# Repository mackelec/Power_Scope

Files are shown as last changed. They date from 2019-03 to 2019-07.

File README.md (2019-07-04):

# Power_Scope
Power Scope for $10

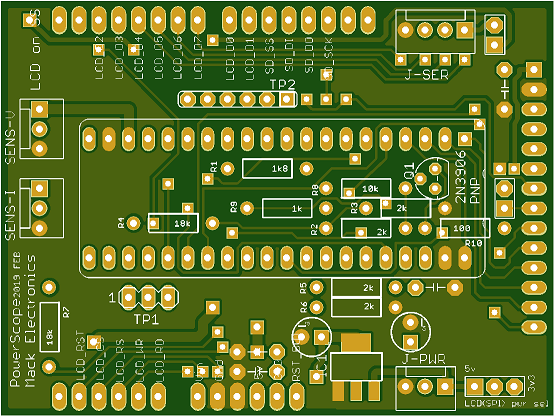
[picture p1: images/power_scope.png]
Power_Scope


https://www.thebackshed.com/forum/forum_posts.asp?TID=11123&PN=1

Software is still a work in progress.

A minimal Oscilloscope design utilising a STM32F103 "Blue Pill" and a cheap mcuFriend 2.4" LCD, specifically to display the output voltage for an Inverter.  Along with displaying th eAc waveform it will display RMS voltage, Current and Power.

LCD library is compatible with the 8bit mcuFriend 2.4" and 3.5" LCD.

PCD features:

PCB is compatible with the 8 bit mcuFriend "UNO" lcds as well as the SPI based LCDs.

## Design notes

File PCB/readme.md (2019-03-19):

"PowerScope_004_PCB_Order_20190317.zip"  contains the files sent for PCB manufacture.

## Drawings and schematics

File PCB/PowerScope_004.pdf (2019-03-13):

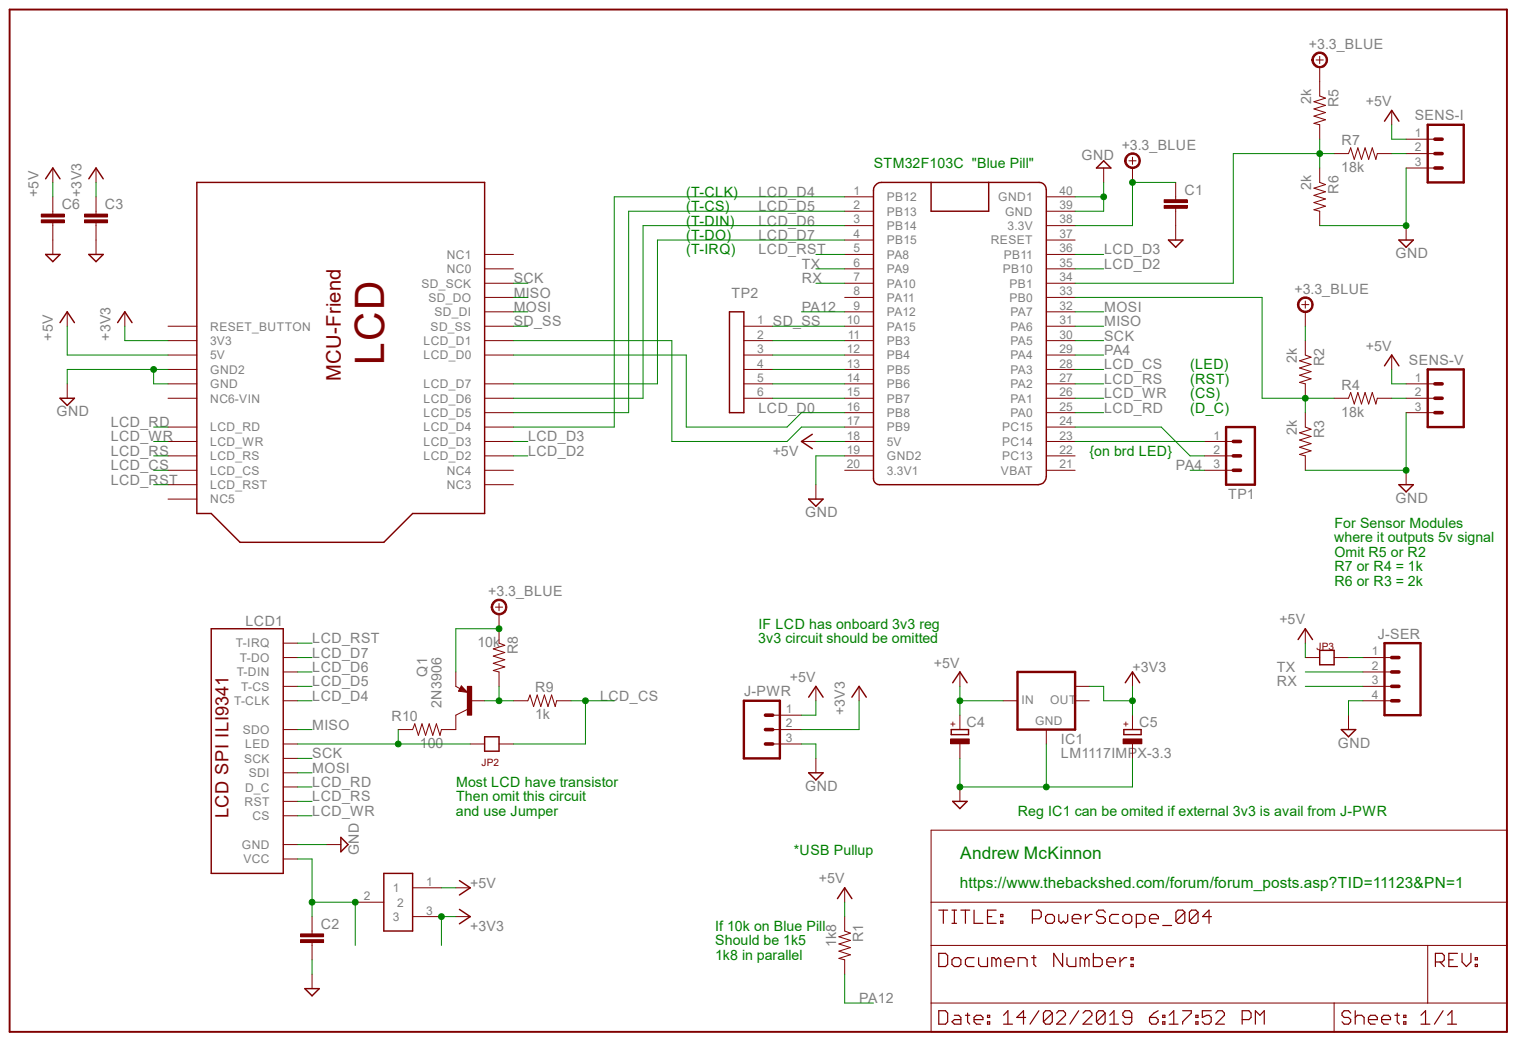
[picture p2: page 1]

For Sensor Modules
where it outputs 5v signal
Omit R5 or R2

IF LCD has onboard 3v3 reg
3v3 circuit should be omitted

Most LCD have transistor
Then omit this circuit

https://www.thebackshed.com/forum/forum_posts.asp?TID=11123&PN=1

If 10k on Blue Pill
Should be 1k5
1k8 in parallel

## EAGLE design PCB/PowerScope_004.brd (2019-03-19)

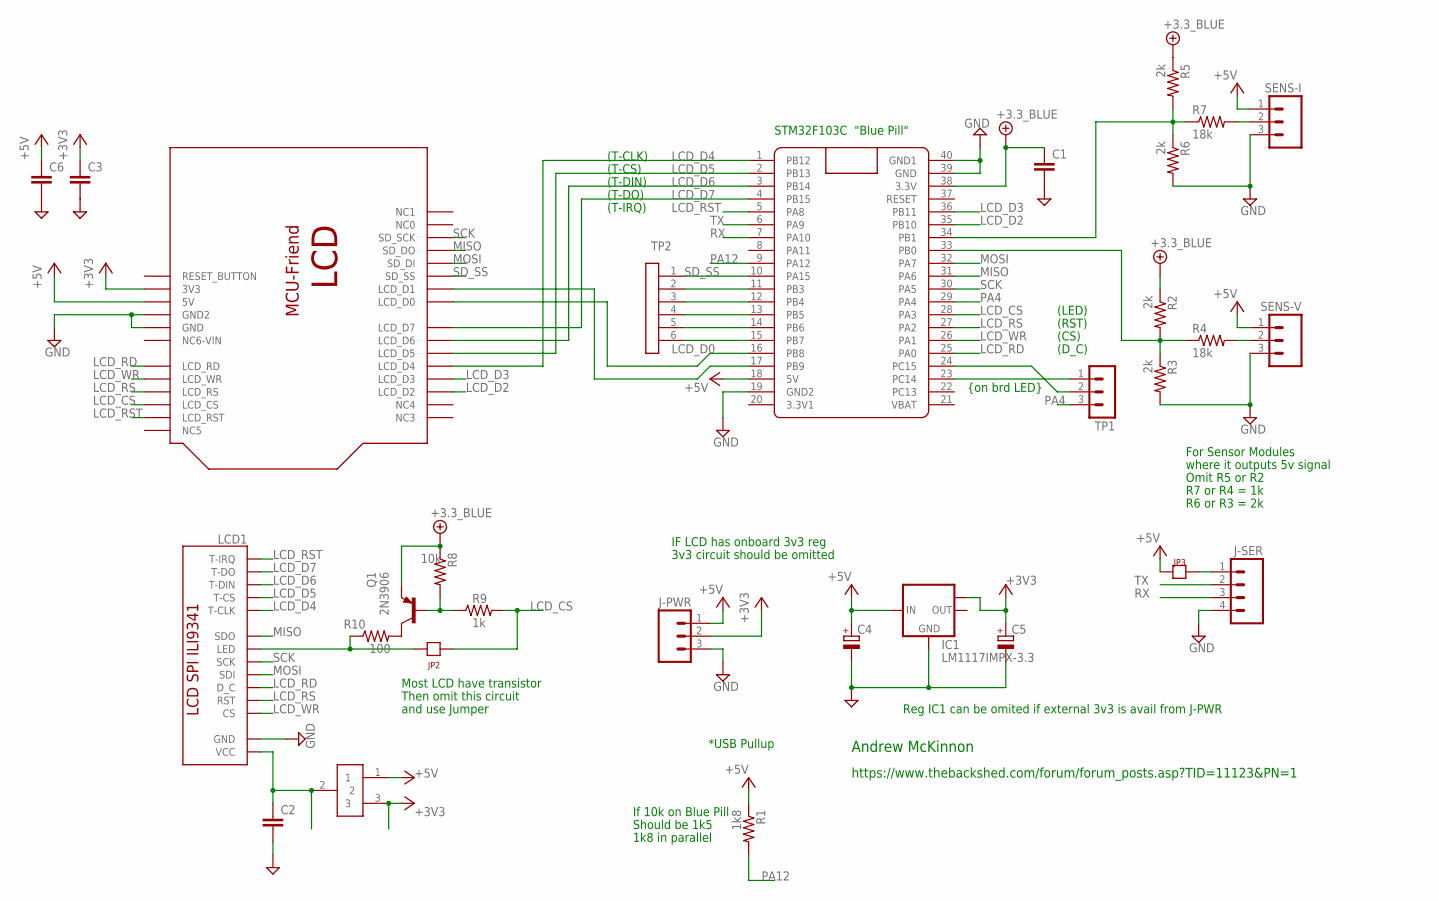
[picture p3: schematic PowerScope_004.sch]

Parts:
C1, C2, C3, C6: BCAP
C4, C5: C-RB200100; CPOL-RADIAL-10UF-25V
IC1: LM1117IMPX-3.3; SOT223
J-PWR: MO3POL; MOLEX-3
J-SER: MO4POL; MOLEX-4
JP1: JP1X3
JP2, JP3: JP1
LCD1: LCD_ILI9341_SPI_TREV; LCD_ILI9341_SPI_24T_REVERSE
Q1: 2N3906; TO92
R1: 1k8; R4_SP
R2, R3, R5, R6: 2k; R4_SP
R4, R7: 18k; R4_SP
R8: 10k; R4_SP
R9: 1k; R4_SP
R10: 100; R4_SP
SENS-I: MO3POL; MOLEX-3
SENS-V: MO3POL; MOLEX-3
TP1: MA03-1
TP2: SIL-6; SIL6
U$2: LCD_MCUFRIENDREV; LCD-MCUFRIEND-24T-REV
U$3: BLUE_PILL; BLUE_PILL_CLEAN

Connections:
+3V3: C3.1, C5.1 (+), IC1.TAB (OUT1), J-PWR.2, JP1.3, U$2.3V (3V3)
+5V: C4.1 (+), C6.1, IC1.3 (IN), J-PWR.1, JP1.1, JP3.1, R1.P$1 (1), SENS-I.1, SENS-V.1, U$2.5V, U$3.18 (5V)
+UB: C1.1, Q1.3 (E), R2.P$1 (1), R5.P$1 (1), R8.P$1 (1), U$3.38 (3.3V)
GND: C1.2, C2.2, C3.2, C4.2 (-), C5.2 (-), C6.2, IC1.1 (GND), J-PWR.3, J-SER.4, LCD1.GND, R3.P$2 (2), R6.P$2 (2), SENS-I.3, SENS-V.3, U$2.GND, U$2.GND2, U$3.19 (GND2), U$3.39 (GND), U$3.40 (GND1)
LCD_CS: JP2.2, R9.P$2 (2), U$2.LCD_CS, U$3.28 (PA3)
LCD_D0: U$2.LCD_D0, U$3.16 (PB8)
LCD_D2: U$2.LCD_D2, U$3.35 (PB10)
LCD_D3: U$2.LCD_D3, U$3.36 (PB11)
LCD_D4: LCD1.T_CLK (T-CLK), U$2.LCD_D4, U$3.1 (PB12)
LCD_D5: LCD1.T_CS (T-CS), U$2.LCD_D5, U$3.2 (PB13)
LCD_D6: LCD1.T_DI (T-DIN), U$2.LCD_D6, U$3.3 (PB14)
LCD_D7: LCD1.T_DO (T-DO), U$2.LCD_D7, U$3.4 (PB15)
LCD_RD: LCD1.D_C, U$2.LCD_RD, U$3.25 (PA0)
LCD_RS: LCD1.RST, U$2.LCD_RS, U$3.27 (PA2)
LCD_RST: LCD1.T-IRQ, U$2.LCD_RST, U$3.5 (PA8)
LCD_WR: LCD1.CS, U$2.LCD_WR, U$3.26 (PA1)
MISO: LCD1.SDO, U$2.SD_DO, U$3.31 (PA6)
MOSI: LCD1.SDI, U$2.SD_DI, U$3.32 (PA7)
unnamed: Q1.2 (B), R8.P$2 (2), R9.P$1 (1)
unnamed: U$2.LCD_D1, U$3.17 (PB9)
unnamed: Q1.1 (C), R10.P$2 (2)
unnamed: TP1.2, U$3.24 (PC15)
unnamed: TP2.6, U$3.15 (PB7)
unnamed: J-SER.1, JP3.2
unnamed: R4.P$2 (2), SENS-V.2
unnamed: R2.P$2 (2), R3.P$1 (1), R4.P$1 (1), U$3.33 (PB0)
unnamed: R7.P$2 (2), SENS-I.2
unnamed: R5.P$2 (2), R6.P$1 (1), R7.P$1 (1), U$3.34 (PB1)
unnamed: TP1.1, U$3.23 (PC14)
unnamed: TP2.5, U$3.14 (PB6)
unnamed: TP2.4, U$3.13 (PB5)
unnamed: TP2.3, U$3.12 (PB4)
unnamed: TP2.2, U$3.11 (PB3)
unnamed: JP2.1, LCD1.LED, R10.P$1 (1)
unnamed: C2.1, JP1.2, LCD1.VCC
PA4: TP1.3, U$3.29 (PA4)
PA12: R1.P$2 (2), U$3.9 (PA12)
RX: J-SER.3, U$3.7 (PA10)
SCK: LCD1.SCK, U$2.SD_SCK, U$3.30 (PA5)
SD_SS: TP2.1, U$2.SD_SS, U$3.10 (PA15)
TX: J-SER.2, U$3.6 (PA9)

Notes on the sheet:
*USB Pullup
If 10k on Blue Pill
Should be 1k5
1k8 in parallel
For Sensor Modules
where it outputs 5v signal
Omit R5 or R2
R7 or R4 = 1k
R6 or R3 = 2k
(RST)
(D_C)
(LED)
(CS)
(T-IRQ)
(T-DO)
(T-DIN)
(T-CS)
(T-CLK)
{on brd LED}
Most LCD have transistor
Then omit this circuit
and use Jumper
Reg IC1 can be omited if external 3v3 is avail from J-PWR
https://www.thebackshed.com/forum/forum_posts.asp?TID=11123&PN=1
Andrew McKinnon
IF LCD has onboard 3v3 reg
3v3 circuit should be omitted
STM32F103C "Blue Pill"

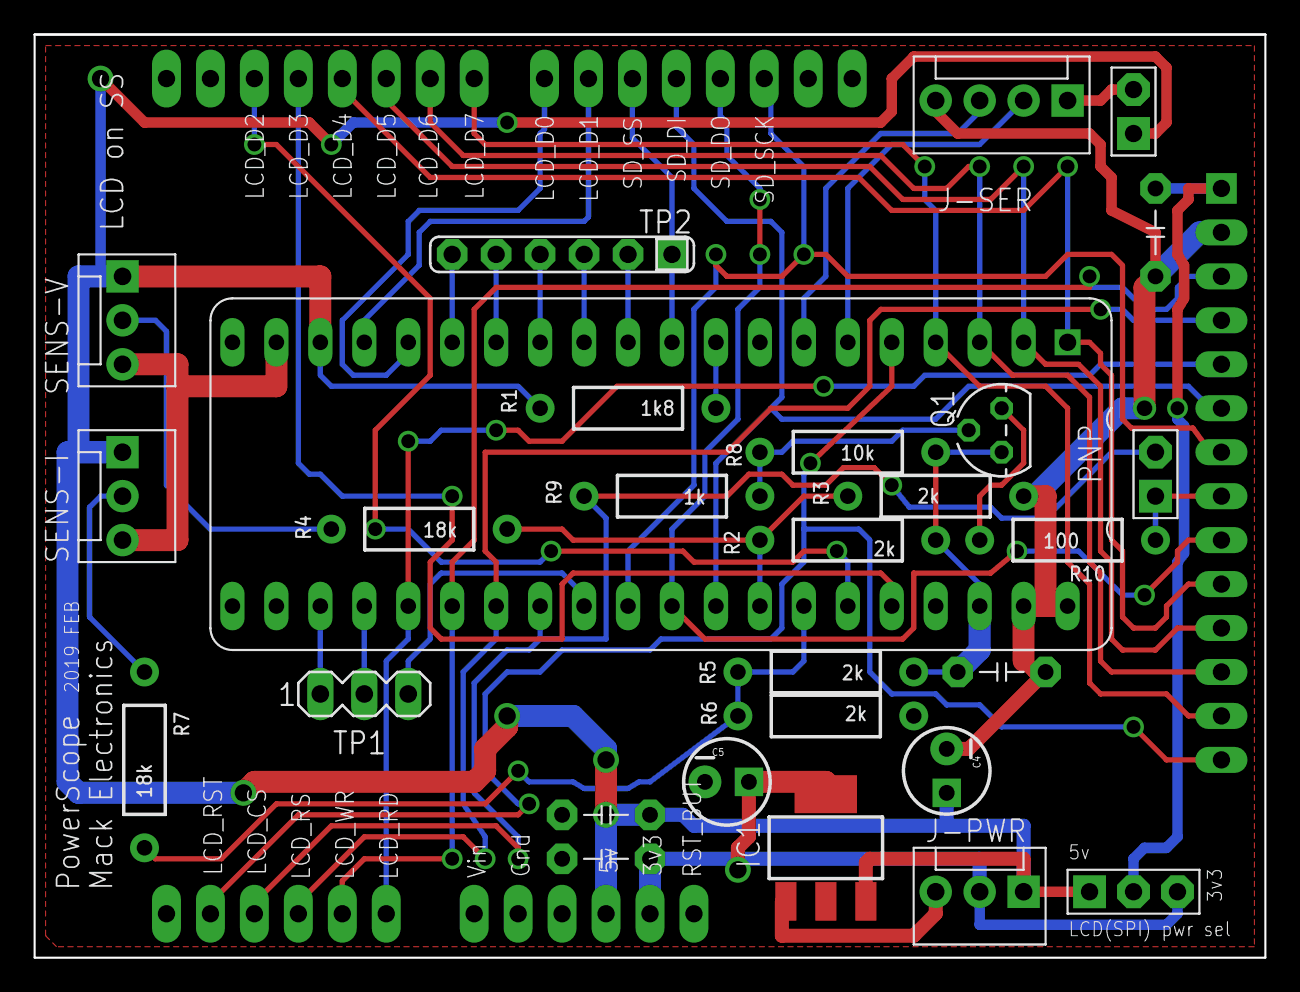
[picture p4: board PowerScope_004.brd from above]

Board: 2 copper layers, 71.1 x 53.3 mm, 30 parts (0 on the bottom side), 41 nets.

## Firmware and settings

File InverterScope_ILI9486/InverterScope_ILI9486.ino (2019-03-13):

/*-------------------------------------------------------------------------------------------------------
 * 
 *   (c) Andrew McKinnon - 2019
 *    
 *    InverterScope - aka Power-Scope   released under the GNU GENERAL PUBLIC LICENSE Version 2, June 1991
 * 
 * 
 --------------------------------------------------------------------------------------------------------*/
#include <SPI.h>  
#include <STM32ADC.h>
#include <Streaming.h>
//#include <Adafruit_GFX.h>
#include "Adafruit_GFX.h"
#include <gfxfont.h>
#include <TouchScreen_STM.h>
//#include "Adafruit_ILI9341_8bit_STM.h" //modified lib for 8-bit parallel displays
#include <MCUFRIEND_kbv.h>

#define LCD_RD PA0
#define LCD_WR PA1
#define LCD_CD PA2
#define LCD_CS PA3
#define LCD_RESET PA8


HardwareTimer adcTimer(4);
STM32ADC adcV(ADC1);
STM32ADC adcI(ADC2);


/*----------------------------
 *    Size of LCD in Landscape
 -----------------------------*/
#define TFT_WIDTH  320
#define TFT_HEIGHT 240

/*----------------------------
 *    Size of Scope (graphing)
 *    -   Must be same / smaller
 *        than TFT_ parameters
 -----------------------------*/

#define FRAME_HEIGHT TFT_HEIGHT
#define FRAME_WIDTH TFT_WIDTH

/*----------------------------
 *  Frame_Period : 
 *  - time in microseconds
  ----------------------------*/

#define FRAME_PERIOD 50000

/*-----------------------------------------
 *    Persist, if True
 *    - last trace will not be erased on LCD
 -----------------------------------------*/
bool Persist = true;

#define testPin1 PA4
#define testPin2 PA5
#define testPin3 PA6

#define LED      PC13

uint8 adcPinV = PB0;
uint8 adcPinI = PB1;

bool testpinFlag;
//bool triggerMode = true;
volatile bool readyForTrigger = false;
volatile bool triggered = false;



volatile uint16 adcValueV=0;
volatile uint16 adcValueI=0;
volatile bool adcV_dataPresent;
volatile bool adcI_dataPresent;

uint16 adcPtr;
uint16 samplesA[FRAME_WIDTH];
uint16 samplesB[FRAME_WIDTH];
uint16 IsamplesA[FRAME_WIDTH];
uint16 IsamplesB[FRAME_WIDTH];
uint16 *samples;
uint16 *adcSamples;

uint16 zeroOffset = 0;
uint16 Vrms = 0;
uint16 Vrms_12bit = 0;
uint16 Vpp_12bit = 0;


uint16 Period_count = 0;   
uint32 Period_us = 0;          //  microseconds
uint16 Frequency = 0;


void setup() {
  //Serial.begin(115200);
  Serial.begin(250000);
  pinMode(testPin1,OUTPUT);
  pinMode(testPin2,OUTPUT);
  pinMode(testPin3,OUTPUT);
  pinMode(LED,OUTPUT);
  digitalWrite(LED,LOW);
  TFT_setup();
  samples = samplesA;
  adcSamples = samples;

  //*******  ADC setup

  adcV.calibrate();
  adcV.setSampleRate(ADC_SMPR_239_5);
  adcV.attachInterrupt(adcConvertedInt, ADC_EOC);
  adcV.setPins(&adcPinV, 1);

  adcI.calibrate();
  adcI.setSampleRate(ADC_SMPR_239_5);
  //adcI.attachInterrupt(int_ADCI,, ADC2_EOC);
  adcI.setPins(&adcPinI, 1);

    // -- sets up the adc control registers
    //    for Dual ADC, simultaneous sample
  ADC1->regs->CR1 |= 0x60000;
  ADC1->regs->CR2 |= 0x100;

  //*******  Timer setup  (156.25 microseconds, 6400Hz)
  //---
  //---  works out perfect for 50Hz
  //---  Frame = 50mS, 2.5 full cycles
  //---  Sample rate = 50ms / 320 (lcd width or frame)
  //---  equals 156.25 uSec - tada
  
  adcTimer.setMode(TIMER_CH4, TIMER_OUTPUT_COMPARE);
  adcTimer.pause();
  adcTimer.setPrescaleFactor(1);
  adcTimer.setCount(0);
  adcTimer.setOverflow(11250);
  adcTimer.setCompare(TIMER_CH4, 1);  
  adcTimer.attachCompare4Interrupt(timer_Handler);
  adcTimer.refresh();

  //********
  
  adcTimer.resume();
  //Serial << "TX buffer = " << SERIAL_TX_BUF_SIZE << endl;
  Serial << "Setup done" << endl;
  Serial.flush();
  digitalWrite(LED,HIGH);
}




void loop() 
{
 
}


void proc_Samples()
{
  if (adcPtr > 319 && adcPtr < 321)
  {
    gpio_write_bit(GPIOA, 6, HIGH);
    triggered = false;
    adcTimer.pause();
    adcPtr = 333;
    readyForTrigger = false;
    drawTrace();
    adcPtr = 0;
    readyForTrigger = true;
    gpio_write_bit(GPIOA, 6, LOW);
    adcTimer.resume();
  }
}

/*---------------------------------------------------------
 * 
 *    ADC callback routine
 *    -  Is called when conversion is finished
 * 
 ---------------------------------------------------------*/

void adcConvertedInt()
{
  static uint16 lastADC = 0;
  gpio_write_bit(GPIOA, 4, LOW);
  //-- read adc 32bit data register
  uint32 data = ADC1->regs->DR;
  adcValueV = data & 0xFFFF;
  adcValueI = data >> 16;

  //------------  If Frame full 
  
  if (adcPtr > 319) 
  {
    if (triggered)
    {
      //gpio_write_bit(GPIOA, 5, LOW);
      if (adcSamples == samplesA)
      {
        samples = samplesA;
        adcSamples = samplesB;
      }
      else
      {
        samples = samplesB;
        adcSamples = samplesA;
      }
      proc_Samples();
    }
    triggered = false;
    
    lastADC = 0;
    return;
  }

  //------------  Saving Frame data
  
  if (triggered)
  {
    //gpio_write_bit(GPIOA, 5, HIGH);
    adcSamples[adcPtr] = adcValueV;
    adcPtr ++;
  }

  //------------  Looking for Trigger
  
  else
  {
    if (lastADC == 0) 
    {
      lastADC = adcValueV;
      return;
    }

    int y1 = (int) (adcValueV - 2048);
    int y2 = (int) (lastADC - 2048);
//    y1 -= (int) zeroOffset;
//    y2 -= (int) zeroOffset;
    lastADC = adcValueV;
    if (y2 < 0 && y1 >= 0)
    {
      triggered = true;
    }
  }
}

/*------------------------------------------------------------
 *    Timer handler - fires every 156.25uSec
 *    -   Starts ADC conversion.
 *        Only needs to Start ADC1 conversion.
 *        As Dual mode is set, ADC2 conversion is started by ADC1.
 *    -   Sets testPin1 HIGH, 
 *        testPin1 is cleared LOW when the ADC callBack Occurs.   
 *        Use a Scope to check timing is good and no over-runs
 -------------------------------------------------------------*/

void timer_Handler()
{
  //----  turn testPin1 high
  gpio_write_bit(GPIOA, 4, HIGH);
  adcV.startConversion();
}

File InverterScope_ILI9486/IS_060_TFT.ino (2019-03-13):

#include <Fonts/FreeMonoBold12pt7b.h>
#include <Fonts/FreeMonoBold9pt7b.h>
#include <Fonts/FreeSansBold9pt7b.h>
#include <Fonts/TomThumb.h> // super small font


#define PORTRAIT 0
#define LANDSCAPE 1

// Display colours
//#define BEAM1_COLOUR ILI9341_GREEN
//#define BEAM2_COLOUR ILI9341_RED
//#define BEAM_OFF_COLOUR ILI9341_BLACK
//#define CURSOR_COLOUR ILI9341_GREEN
#define BEAM_OFF_COLOUR TFT_BLACK
#define BEAM1_COLOUR TFT_GREEN
#define BEAM2_COLOUR TFT_RED
#define CURSOR_COLOUR TFT_GREEN

#define GRATICULE_COLOUR 0x07FF

//  http://www.barth-dev.de/online/rgb565-color-picker/
#define BLUE1 0x001F
#define WHITE 0xFFFF
#define GREY1 0x6B6D
#define GREY2 0x4A69
#define GREY3 0x2965
#define YELLOW 0xFFE0

//Adafruit_ILI9341_8bit_STM TFT = Adafruit_ILI9341_8bit_STM();
MCUFRIEND_kbv TFT;

uint16_t myHeight,myWidth;

uint8 traceA[FRAME_WIDTH];
uint8 traceB[FRAME_WIDTH];
uint8 *trace;
uint8 *lastTrace = 0; 
uint16 lastVrms;

int16 dataVAC[FRAME_WIDTH];


void drawTrace()
{
  
  static uint8 cnt=0;
  
//  zeroOffset = currentOffset(samples);
//  convert2AC(samples,dataVAC);
//  Period_count =  periodCount(dataVAC);
//  Vrms_12bit = RMS(samples,&Vpp_12bit);

  stats_Sample(samples);
  
  
  if (lastTrace == 0 || lastTrace == traceB)
  {
    trace = traceB;
    lastTrace = traceA;
  }
  else
  {
    trace = traceA;
    lastTrace = traceB;
  }
  convert2Trace(samples,trace);
  TFT.setRotation(LANDSCAPE);
  for (int i=0;i < 320;i++)
  {
    if (! Persist)
    {
      if (lastTrace[i] > 0) TFT.drawPixel(i,lastTrace[i],BEAM_OFF_COLOUR);
    }
    TFT.drawPixel(i,trace[i],BEAM1_COLOUR);
  }
  //showGraticule();
  cnt ++;
  if (cnt > 16 && Vrms != lastVrms)
  {
    cnt=0;
    drawVrms();
  }
}


void TFT_setup()
{
  uint16_t ID = TFT.readID(); //
    Serial.print("ID = 0x");
    Serial.println(ID, HEX);
    if (ID == 0xD3D3) ID = 0x9481; // write-only shield
//    ID = 0x9329;                             // force ID
    TFT.begin(ID);
  
  //TFT.begin();
  clearTFT();
  TFT.setRotation(PORTRAIT);
  myHeight   = TFT.width();
  myWidth  = TFT.height();
  TFT.setTextColor(CURSOR_COLOUR, BEAM_OFF_COLOUR);
  TFT.setRotation(LANDSCAPE);
  showSplash();
  delay(3000);
  clearTFT();
  showGraticule();
  drawVoltRect();
}


void drawVrms()
{
  static uint16 lastJunk=0;
  
  TFT.setFont(&FreeMonoBold9pt7b);
  TFT.setRotation(LANDSCAPE);
  //drawVoltRect();
  TFT.setTextColor(GREY3, GREY3);
  TFT.setCursor(15, 30);
  TFT.print(lastVrms);
  TFT.setFont(&TomThumb);
  TFT.setTextSize(2);
  TFT.print(" Vrms");

  TFT.setFont(&FreeMonoBold9pt7b);
  TFT.setRotation(LANDSCAPE);
  //drawVoltRect();
  TFT.setTextColor(BEAM_OFF_COLOUR, BEAM_OFF_COLOUR);
  TFT.setCursor(135, 30);
  TFT.print(lastJunk);
  

  TFT.setRotation(LANDSCAPE);
  TFT.setFont(&FreeMonoBold9pt7b);
  TFT.setTextColor(YELLOW, GREY3);
  TFT.setCursor(15, 30);
  TFT.print(Vrms);
  TFT.setFont(&TomThumb);
  TFT.setTextSize(2);
  TFT.print(" Vrms");
  lastVrms = Vrms;

  TFT.setRotation(LANDSCAPE);
  TFT.setFont(&FreeMonoBold9pt7b);
  TFT.setTextColor(YELLOW, BEAM_OFF_COLOUR);
  TFT.setCursor(135, 30);
  TFT.print(Frequency);
  lastJunk = (uint16) Frequency;
}

void drawVoltRect()
{
  TFT.setRotation(LANDSCAPE);
  TFT.fillRoundRect(1,1,120,40,10,GREY3);
  TFT.drawRoundRect(1,1,120,40,10,WHITE);
}



/*--------------------------------------------------
 *   Chunks of code borrowed from STM-O-Scope 
 ---------------------------------------------------*/

void clearTFT()
{
  TFT.fillScreen(BEAM_OFF_COLOUR);          // Blank the display
}

void showGraticule()
{
  TFT.setRotation(PORTRAIT);     
  TFT.drawRect(0, 0, TFT_HEIGHT, TFT_WIDTH, GRATICULE_COLOUR);
  // Dot grid - ten distinct divisions (9 dots) in both X and Y axis.
  for (uint16_t TicksX = 1; TicksX < 10; TicksX++)
  {
    for (uint16_t TicksY = 1; TicksY < 10; TicksY++)
    {
      TFT.drawPixel(  TicksX * (myHeight / 10), TicksY * (myWidth / 10), GRATICULE_COLOUR);
    }
  }

  int edge_interrupt_falling = 3;   // show more dots for the falling interrupt edge, which may be used for frequency counting
  for (int TicksY = 1; TicksY < 20; TicksY++)
  {
    TFT.drawPixel(  edge_interrupt_falling * (myHeight / 10), TicksY * (myWidth / 20), GRATICULE_COLOUR);
  }

  // Horizontal and Vertical centre lines 5 ticks per grid square with a longer tick in line with our dots
  for (uint16_t TicksX = 0; TicksX < myWidth; TicksX += (myHeight / 50))
  {
    if (TicksX % (myWidth / 10) > 0 )
    {
      TFT.drawFastHLine(  (myHeight / 2) - 1, TicksX, 3, GRATICULE_COLOUR);
    }
    else
    {
      TFT.drawFastHLine(  (myHeight / 2) - 3, TicksX, 7, GRATICULE_COLOUR);
    }

  }
  for (uint16_t TicksY = 0; TicksY < myHeight; TicksY += (myHeight / 50) )
  {
    if (TicksY % (myHeight / 10) > 0 )
    {
      TFT.drawFastVLine( TicksY,  (myWidth / 2) - 1, 3, GRATICULE_COLOUR);
    }
    else
    {
      TFT.drawFastVLine( TicksY,  (myWidth / 2) - 3, 7, GRATICULE_COLOUR);
    }
  }
}

void showSplash() 
{
    TFT.setTextSize(2);                     // Small 26 char / line
    //TFT.setTextColor(CURSOR_COLOUR, BEAM_OFF_COLOUR) ;
    int YStep = 20;
    int YStart = 20;
    TFT.setCursor(0, YStart);
    TFT.print("     InverterScope");
    TFT.setCursor(0, YStart+=2*YStep);
    TFT.print("5mSec/div  50mSec Frame");
    TFT.setCursor(0, YStart+=YStep);
    TFT.print("320 samples / frame");
    TFT.setCursor(0, YStart+=2*YStep);
    TFT.print("   ");
    TFT.setCursor(0, YStart+=1.5*YStep);
    TFT.print("Max MCU Pin Voltage: 3.3V");
    TFT.setCursor(0, YStart+=YStep);
    TFT.print("");
    TFT.setCursor(0, YStart+=YStep);
    TFT.print("");
    TFT.setTextSize(2);
    TFT.setRotation(PORTRAIT);
}
